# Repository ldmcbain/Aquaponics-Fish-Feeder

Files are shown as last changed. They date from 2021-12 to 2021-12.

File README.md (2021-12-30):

# Aquaponics Fish Feeder
 ESP32 Aquaponics Fish Feeder

This is a mod of a design I found in thingiverse:
https://www.thingiverse.com/thing:497637

This was designed using an ESP32 devkit board along with a 28BYJ-48 stepper motor and ULN2003 driver board (amazon).

The ESP32 is setup to create a WIFI captive portal page which is used to setup timing on the fish feeding intervals.  You can set the time/date on the device but know that it will loose the time/date on power reset.  However the feeding interval is stored in EEPROM, so it will just reset the clock to midnight and keep on going if power is interrupted.  This is designed only for a few fish, thus the small feeder holes.  The design was changed from the original as i found that the food we used would go underneath the original paddle wheels.

I also conformal coated the ESP board and driver board before deploying it (MG Chemicals - 422C-55MLCA 422C Silicone Conformal Coating - available from amazon)

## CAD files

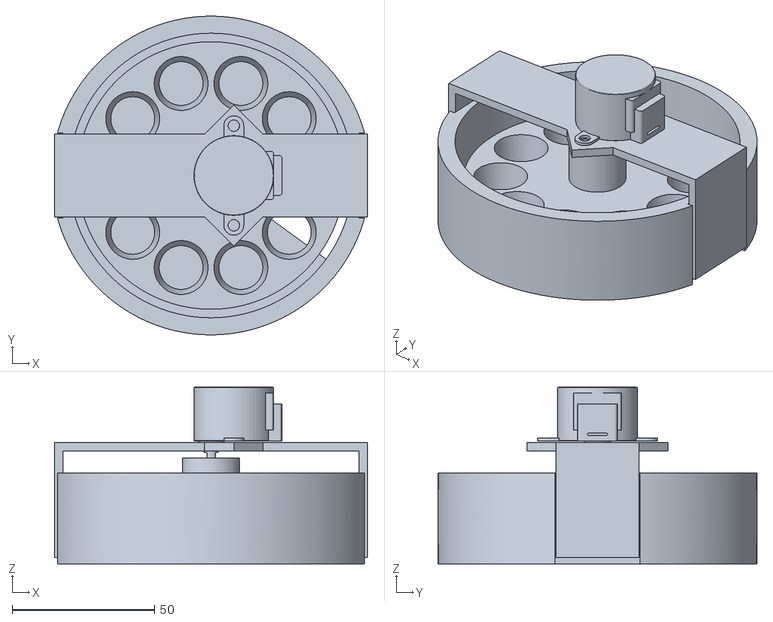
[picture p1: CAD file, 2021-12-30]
3D Printed Parts/Entire feeder.stl
110.0 x 112.0 x 62.1

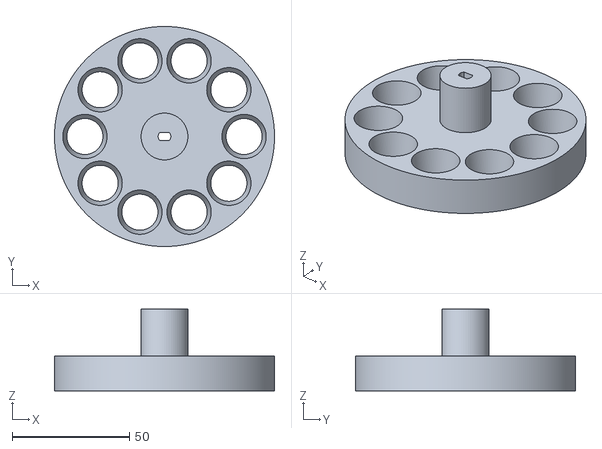
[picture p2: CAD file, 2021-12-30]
3D Printed Parts/NewDivider.stl
94.0 x 94.0 x 35.0

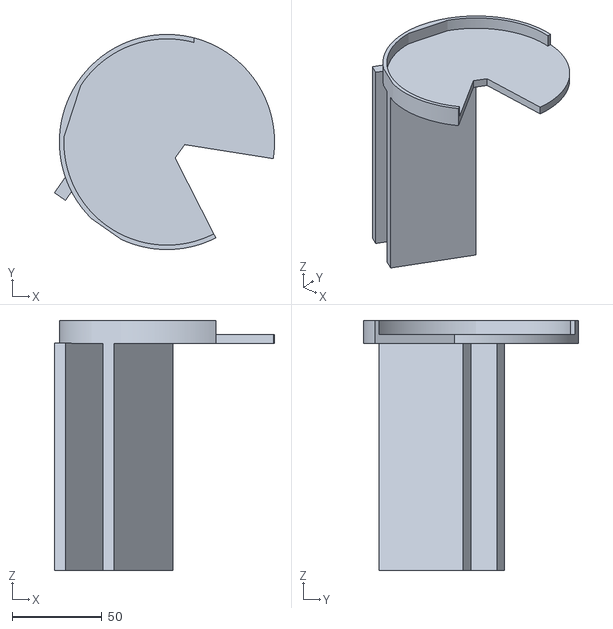
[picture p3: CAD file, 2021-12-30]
3D Printed Parts/feederBracket.stl
122.8 x 120.0 x 139.4

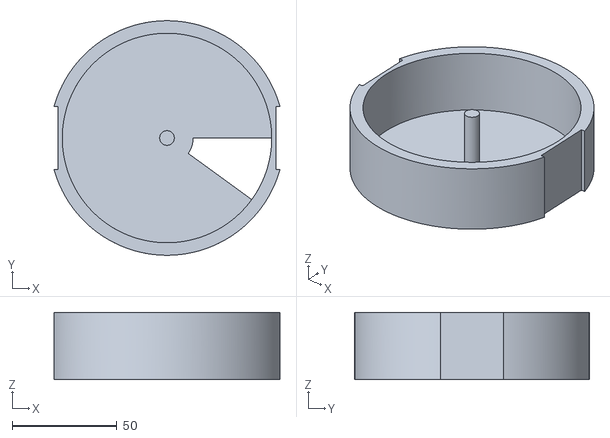
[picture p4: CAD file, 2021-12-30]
3D Printed Parts/Speedy_Feeder_v2_Container.stl
107.9 x 112.0 x 32.0

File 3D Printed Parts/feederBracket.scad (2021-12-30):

$fa=1;
$fs=1;

in=25.4;
th=5;
angle=-125;

%rotate([0,0,-18])
translate([0,0,th])
import("entire feeder.stl",convexity=4);
bracket();


module bracket()
{
    inner=115;
    difference()
    {
        cylinder(d=inner+th,h=0.5*in);
        translate([0,0,th])
        cylinder(d=inner,h=1*in);
        
        *translate([10,-inner/4,-th])
        cube([inner,inner/4,1*in]);
        
        rotate([0,0,-9])
        translate([0,0,-20])
        hull()
        {
            translate([10,0,0])
            cube([100,0.1,100]);
            rotate([0,0,-54])
            translate([10,0,0])
            cube([100,0.1,100]);
        }
        
        rotate([0,0,angle+90])
        translate([0,-50-inner/2-th/3,0])
        cube([100,100,600],center=true);
        
    
    translate([15,-10,th])
    cube([100,100,100]);
    }
    
    rotate([0,0,-18])
    translate([-inner/2-0.5,-30/2,0])
    cube([th/2,30,0.5*in]);
    
    rotate([0,0,angle])
    translate([0,-15,0])
    difference()
    {
        translate([th/3,-(1*in+th*3)/2,-4.99*in])
        cube([(inner)/2,1*in+th*3,5*in]);
        cube([(inner)*2,1*in,50*in],center=true);
    }
}

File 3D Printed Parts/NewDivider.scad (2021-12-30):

$fa=1;
$fs=1;
in=25.4;


difference()
{
    union()
    {//making small on purpose to reduce friction along edges
    cylinder(d=94,h=15);
    cylinder(d=20,h=35);
    }
    
    for(i=[0:10])
    {
        rotate([0,0,i*360/10])
        translate([34,0,25])
        {
        //scale([1,1,2])
        //sphere(d=24);
            
        cylinder(d1=0.375*in,d2=33,h=100,center=true);
        }
    }
    
    translate([0,0,-0.01])
    cylinder(d=9.5,h=30);
    
    intersection()
    {
        cylinder(d=5.5,h=100);
        cube([10,3.5,100],center=true);
    }
    
}

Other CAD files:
3D Printed Parts/Speedy_Feeder_v2_Divider_modv2.3mf
3D Printed Parts/Motor_Bracket.stl

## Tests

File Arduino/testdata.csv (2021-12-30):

20210708_0500 | wt | 70
20210708_0530 | wt | 71
20210708_0600 | wt | 70
20210708_0630 | wt | 71
20210708_0700 | wt | 70
20210708_0730 | wt | 71
20210708_0800 | wt | 70
20210708_0830 | wt | 71
20210708_0900 | wt | 70
20210708_0930 | wt | 71
20210708_1000 | wt | 70
20210708_1030 | wt | 70
20210708_1100 | wt | 71
20210708_1130 | wt | 70
20210708_1200 | wt | 71
20210708_1230 | wt | 70
20210708_1300 | wt | 71
20210708_1330 | wt | 70
20210708_1400 | wt | 71
20210708_1430 | wt | 70
20210708_1500 | wt | 71
20210708_1530 | wt | 70
20210708_1600 | wt | 71
20210708_1630 | wt | 70
20210708_1700 | wt | 70
20210708_1730 | wt | 70
20210708_1800 | wt | 70
20210708_1830 | wt | 70
20210708_1900 | wt | 70
20210708_1930 | wt | 70
20210708_2000 | wt | 70
20210708_2030 | wt | 70
20210708_2100 | wt | 70
20210708_2130 | wt | 70
20210708_2200 | wt | 71

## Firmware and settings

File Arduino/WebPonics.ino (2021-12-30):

/*
 * ENDEAVOR Web based Aquaponics Controller
 * This project was created by Endeavor Labs (a mission of Endeavor Church) to create
 * an Arduino based controller to service an aquaponics setup meant for a class setting.
 * 
 * The system is to be designed to use a ESP32 Dev board to control:
 *  - 3D printed fish feeder driven by servo motor
 *      Based on https://www.thingiverse.com/thing:4627735, modified to hook onto tank
 *  - Water temperature sensor
 *  - Air Temperature/Humidity sensor
 *  - Water level sensor
 *  - Pump cutoff based upon low water level reading
 *  - Real Time Clock (RTC) / Data loger (SD card) used for obtaining date/time for feeding etc
 *  - Web based interface for viewing data, manual feed control, data log entry and viewing. (stored on SD card)
 * 
 * This software is designed to create a permanent Access Point with a captive portal
 * to a webpage which will control the Feeder and view/monitor sensors and logs as noted above
 * 
 * Will utilize Plotly JS script library (plotly.js stored in SPIFFS) to view data graphs.
 * Stored data logs and sensor logs will be stored on SD card
 * 
 * I have found partial plotly files which will likely work and are much smaller.  using minimized basic package located here:
 * https://github.com/plotly/plotly.js/blob/master/dist/README.md
 * also possible to create own package customized to only what I need:
 * https://github.com/plotly/plotly.js/blob/master/CUSTOM_BUNDLE.md
 * Note: I may have issues w/ plotly as it is LARGE and unsure how to reference a JS file on an SD card.
 * Alternatives may be required.
 * https://forum.arduino.cc/t/arduino-mega-json-rest-interfaces-for-html-guis/126471/9
 * 
 * 
 * Note for possible future upgrade.. ability to upload data directly to web based server.
 * current use is offline-only.
 *      https://github.com/plotly/arduino-api
 *      https://www.instructables.com/Plotly-Arduino-Data-Visualization/
 * 
 * This version is based upon initial work with the Endeavor Sign V2 and is using that project
 * as a base.  It may possibly also utilize the Endeavor Labs ESP32 board.
 * 
 * Board - ESP32S Dev Module (thin version of ESP module [22.86mm pin width] from HiLetgo ESP-WROOM-32S)
 *          I believe this is a NodeMCU ESP32S board design https://www.amazon.com/gp/product/B0718T232Z/ref=ppx_yo_dt_b_search_asin_title?ie=UTF8&psc=1)
 * Upload Speed - 115200
 * CPU Freq - 240MHz
 * Flash Freq 40MHz
 * Mode - QIO
 * Flash size - 4MB (32Mb)
 * Partition - Default 4MB wigh SPIFFS (1.2MB APP/1.5MB SPIFFS)
 */

#include <Arduino.h>
#include <WebServer.h>
#include <DNSServer.h>
#include "./server_html.h"
#include "./myeeprom.h"
#include <SPIFFS.h>
#include <Wire.h>
#include "RTClib.h"
#include "DST_RTC.h"

#define FILESYSTEM SPIFFS

//motor pins
#define MOTOR_A 12
#define MOTOR_B 13
#define MOTOR_C 14
#define MOTOR_D 15
#define NUMBER_OF_STEPS_PER_REV 512


// Replace with your network credentials
const char* ssid     = "AQUA_P_";
const char* password = NULL;  //making this an open access?

// Set web server port number to 80
WebServer server(80);
const byte DNS_PORT = 53;
IPAddress apIP(192, 168, 1, 1);
DNSServer dnsServer;

RTC_DS1307 rtc; // clock object
DST_RTC dst_rtc; // DST object
const char rulesDST[]="US";

uint8_t Alarm1, Alarm2, Alarm3, Alarm4;

void handleRoot()
{
  buildWebsite();
  server.send(200, "text/html", webSite);
}

void handleFeed()
{
  //Manually engage servo to feed fish
  Serial.printf("%02i/%02i/%i_%02i:%02i:%02i - Feeding Fish..\n",month(),day(),year(),hour(),minute(),second());
  moveDeg(36);
  MotorOff();
}

void handleSetTime()
{
  //set the time based upon something from the website..
  //Serial.printf("attempting to set time to: %s/%s/%s %s:%s:%s",server.arg("MM"),server.arg("D"),server.arg("Y"),server.arg("H"),server.arg("m"),server.arg("s"));
  //Serial.println("");
  settime(atoi(server.arg("MM").c_str()),
          atoi(server.arg("D").c_str()),
          atoi(server.arg("Y").c_str()),
          atoi(server.arg("H").c_str()),
          atoi(server.arg("m").c_str()),
          atoi(server.arg("s").c_str()));
}

void settime(int Month, int Day, int Year, int Hour, int Min, int Sec)
{
  //set the RTC time clock
  rtc.adjust(DateTime(Year, Month, Day, Hour, Min, Sec));
  Serial.printf("Time set to: %02i/%02i/%i %02i:%02i:%02i",Month,Day,Year,Hour,Min,Sec);
  Serial.println("");
  //init time for time.h
  setTime(Hour, Min, Sec, Day, Month, Year);
  
  // DST? If we're in it, let's subtract an hour from the RTC time to keep our DST calculation correct. This gives us
  // Standard Time which our DST check will add an hour back to if we're in DST.
  DateTime standardTime = now();
  if (dst_rtc.checkDST(standardTime) == true) { // check whether we're in DST right now. If we are, subtract an hour.
    standardTime = standardTime.unixtime() - 3600;
    rtc.adjust(standardTime);
    Serial.println("Time adjusted for Daylight Savings Time");
  }
}

//function will parse out a time in string format "HH:MMam" to integers
void ParseTime(char* Instr, int* Hour, int* Min, bool* AM)
{
  //char param[10];
  char out[3] = "";
  int colon;
  colon=0;
  //strcopy(param,Instr);
  for(int i=0;i<strlen(Instr);i++)
  {
    if(Instr[i]==':')
    {
      out[i]=0;
      *Hour=atoi(out);
      colon=i+1;
      out[0]=0;
    } else if((Instr[i]!='a') && (Instr[i]!='p'))
    {
      out[i-colon]=Instr[i];
    } else
    {
      out[i]=0;
      *Min=atoi(out);
      if(Instr[i]=='a') *AM=true; else *AM=false;
    }
  }
}

//clear existing alarms and set new ones.
void handleSetAlarms()
{
  int Hour, Min;
  bool AM;
  char instr[10];

  if(Alarm.isAllocated(Alarm1))
  {
    Alarm.disable(Alarm1);
    Alarm.free(Alarm1);
    Serial.println("Alarm1 Freed");
  }
  if(Alarm.isAllocated(Alarm2))
  {
    Alarm.disable(Alarm2);
    Alarm.free(Alarm2);
    Serial.println("Alarm1 Freed");
  }
  if(Alarm.isAllocated(Alarm3))
  {
    Alarm.disable(Alarm3);
    Alarm.free(Alarm3);
    Serial.println("Alarm1 Freed");
  }
  if(Alarm.isAllocated(Alarm4))
  {
    Alarm.disable(Alarm4);
    Alarm.free(Alarm4);
    Serial.println("Alarm1 Freed");
  }
  
  if(server.hasArg("E1"))
  {
    strcpy(instr,server.arg("E1").c_str());
    T1_time = server.arg("E1");
    ParseTime(instr,&Hour,&Min, &AM);
    if(AM && (Hour==12)) Hour = 0;
    if(!AM && (Hour!=12)) Hour += 12;
    Serial.printf("Event1 set for: %02i:%02i:00\n",Hour,Min);
    //sprintf(T1_time,"%02i:%02i\n",Hour,Min);
    T1_e = true;

    Alarm1 = Alarm.alarmRepeat(Hour,Min,0,handleFeed);
  } else T1_e = false;
  if(server.hasArg("E2"))
  {
    strcpy(instr,server.arg("E2").c_str());
    T2_time = server.arg("E2");
    ParseTime(instr,&Hour,&Min, &AM);
    if(AM && (Hour==12)) Hour = 0;
    if(!AM && (Hour!=12)) Hour += 12;
    Serial.printf("Event2 set for: %02i:%02i:00\n",Hour,Min);
    T2_e = true;
    
    Alarm2 = Alarm.alarmRepeat(Hour,Min,0,handleFeed);
  } else T2_e = false;
  if(server.hasArg("E3"))
  {
    strcpy(instr,server.arg("E3").c_str());
    T3_time = server.arg("E3");
    ParseTime(instr,&Hour,&Min, &AM);
    if(AM && (Hour==12)) Hour = 0;
    if(!AM && (Hour!=12)) Hour += 12;
    Serial.printf("Event3 set for: %02i:%02i:00\n",Hour,Min);
    //sprintf(T3_time,"%02i:%02i\n",Hour,Min);
    T3_e = true;
  
    Alarm3 = Alarm.alarmRepeat(Hour,Min,0,handleFeed);
  } else T3_e = false;
  if(server.hasArg("E4"))
  {
    strcpy(instr,server.arg("E4").c_str());
    T4_time = server.arg("E4");
    ParseTime(instr,&Hour,&Min, &AM);
    if(AM && (Hour==12)) Hour = 0;
    if(!AM && (Hour!=12)) Hour += 12;
    Serial.printf("Event4 set for: %02i:%02i:00\n",Hour,Min);
    //sprintf(T4_time,"%02i:%02i\n",Hour,Min);
    T4_e = true;
  
    Alarm4 = Alarm.alarmRepeat(Hour,Min,0,handleFeed);
  } else T4_e = false;
  handleSAVE();
}


time_t syncProvider()
{
  DateTime standardTime = rtc.now();
  
  DateTime theTime = dst_rtc.calculateTime(standardTime); // takes into account DST
  return theTime.unixtime();
}


void handleSAVE()
{
  Serial.println("Saving Settings");
  
  Serial.printf("T1-%s %s\n",T1_time,T1_e ? "Enabled" : "Disabled");
  Serial.printf("T2-%s %s\n",T2_time,T2_e ? "Enabled" : "Disabled");
  Serial.printf("T3-%s %s\n",T3_time,T3_e ? "Enabled" : "Disabled");
  Serial.printf("T4-%s %s\n",T4_time,T4_e ? "Enabled" : "Disabled");
  
  saveSettings(T1_time,T2_time,T3_time,T4_time,T1_e,T2_e,T3_e,T4_e);
}

void handleRESTORE()
{
  int Hour, Min;
  bool AM;
  char instr[10];
  
  getStoredSettings();
  T1_time=String(romSettings.T1);
  T2_time=String(romSettings.T2);
  T3_time=String(romSettings.T3);
  T4_time=String(romSettings.T4);
  T1_e = romSettings.T1_enable;
  T2_e = romSettings.T2_enable;
  T3_e = romSettings.T3_enable;
  T4_e = romSettings.T4_enable;

  if(T1_e)
  {
    strcpy(instr,T1_time.c_str());
    ParseTime(instr,&Hour,&Min, &AM);
    if(AM && (Hour==12)) Hour = 0;
    if(!AM && (Hour!=12)) Hour += 12;
    Serial.printf("Event1 set for: %02i:%02i:00\n",Hour,Min);  
    Alarm1 = Alarm.alarmRepeat(Hour,Min,0,handleFeed);
  }
  if(T2_e)
  {
    strcpy(instr,T2_time.c_str());
    ParseTime(instr,&Hour,&Min, &AM);
    if(AM && (Hour==12)) Hour = 0;
    if(!AM && (Hour!=12)) Hour += 12;
    Serial.printf("Event2 set for: %02i:%02i:00\n",Hour,Min);  
    Alarm2 = Alarm.alarmRepeat(Hour,Min,0,handleFeed);
  }
  if(T3_e)
  {
    strcpy(instr,T3_time.c_str());
    ParseTime(instr,&Hour,&Min, &AM);
    if(AM && (Hour==12)) Hour = 0;
    if(!AM && (Hour!=12)) Hour += 12;
    Serial.printf("Event3 set for: %02i:%02i:00\n",Hour,Min);  
    Alarm3 = Alarm.alarmRepeat(Hour,Min,0,handleFeed);
  }
  if(T4_e)
  {
    strcpy(instr,T4_time.c_str());
    ParseTime(instr,&Hour,&Min, &AM);
    if(AM && (Hour==12)) Hour = 0;
    if(!AM && (Hour!=12)) Hour += 12;
    Serial.printf("Event4 set for: %02i:%02i:00\n",Hour,Min);  
    Alarm4 = Alarm.alarmRepeat(Hour,Min,0,handleFeed);
  }
}

//function will parse out a time in string format "HH:MMam" to integers
void parseStored(char* Instr, int* Hour, int* Min, bool* AM)
{
  //char param[10];
  char out[3] = "";
  int colon;
  colon=0;
  //strcopy(param,Instr);
  for(int i=0;i<strlen(Instr);i++)
  {
    if(Instr[i]==':')
    {
      out[i]=0;
      *Hour=atoi(out);
      colon=i+1;
      out[0]=0;
    } else if((Instr[i]!='a') && (Instr[i]!='p'))
    {
      out[i-colon]=Instr[i];
    } else
    {
      out[i]=0;
      *Min=atoi(out);
      if(Instr[i]=='a') *AM=true; else *AM=false;
    }
  }
}

void setup() {
  Serial.begin(115200);
  
  //Initialize Clock
  Wire.begin();
  rtc.begin();
  
  /*
    This line sets the RTC with an explicit date & time (standard time - not DST), for example to set
    March 28, 2020 at 23:58:5 you would call:
    // rtc.adjust(DateTime(2020, 3, 28, 23, 58, 5));
    If used load the sketch a second time with this line commented out or the RTC will reset to
    this time on power up or reset.
  */
  
  if (! rtc.isrunning()) {
    Serial.println("RTC is NOT running!");
    // following line sets the RTC to the date & time this sketch was compiled
    rtc.adjust(DateTime(__DATE__, __TIME__));
    // DST? If we're in it, let's subtract an hour from the RTC time to keep our DST calculation correct. This gives us
    // Standard Time which our DST check will add an hour back to if we're in DST.
    /*
    DateTime standardTime = rtc.now();
    if (dst_rtc.checkDST(standardTime) == true) { // check whether we're in DST right now. If we are, subtract an hour.
      standardTime = standardTime.unixtime() - 3600;
      rtc.adjust(standardTime);
    }
    */
    
  }
  //setSyncProvider(syncProvider);
  if (timeStatus()!=timeSet)
  {
    //give a default time if power lost so feeder will continue.
    settime(1,1,2021,1,0,0);
  }

  //may need to comment this out for the 1st run to init the save points first
  handleRESTORE();

  //Create and initialize alarms
  /*Alarm1 = Alarm.alarmRepeat(0,0,0,nullFunction);
  Alarm2 = Alarm.alarmRepeat(1,0,0,nullFunction);
  Alarm3 = Alarm.alarmRepeat(2,0,0,nullFunction);
  Alarm4 = Alarm.alarmRepeat(3,0,0,nullFunction);
  Alarm.disable(Alarm1);
  Alarm.disable(Alarm2);
  Alarm.disable(Alarm3);
  Alarm.disable(Alarm4);*/
  //todo - load from eprom stored values.

  // Initialize SPIFFS
  if(!FILESYSTEM.begin(true)){
    Serial.println("An Error has occurred while mounting SPIFFS");
    return;
  }
  
  // Connect to Wi-Fi network with SSID and password
  Serial.print("Starting AP ");
  Serial.println(ssid);

  //set SSID based upon the mac address of the device (in case we have multiple)
  //strcat(ssid,WiFi.softAPmacAddress().c_str());
  WiFi.mode(WIFI_AP);
  Serial.println(WiFi.softAP(ssid, password) ? "soft-AP setup": "Failed to connect");
  delay(100);
  Serial.println(WiFi.softAPConfig(apIP, apIP, IPAddress(255, 255, 255, 0))? "Configuring Soft AP" : "Error in Configuration");


  //setup captive portal so all traffic goes to main page
  dnsServer.start(DNS_PORT, "*", apIP);
  
  Serial.println("");
  Serial.println("WiFi connected.");
  Serial.print("IP:");
  Serial.println(WiFi.softAPIP());
  startWebServer();

  
  pinMode(MOTOR_A,OUTPUT);
  pinMode(MOTOR_B,OUTPUT);
  pinMode(MOTOR_C,OUTPUT);
  pinMode(MOTOR_D,OUTPUT);
}

void loop(){
  //DateTime standardTime = rtc.now();

  //Serial.println("Standard Time");
  //printTheTime(standardTime);
  
  //DateTime theTime = dst_rtc.calculateTime(standardTime); // takes into account DST

  //Serial.println("time adjusted for Daylight Saving Time");
  //printTheTime(theTime);
  
  dnsServer.processNextRequest();
  server.handleClient();
  Alarm.delay(1);
}


// print time to serial
void printTheTime(DateTime theTimeP) {
  Serial.print(theTimeP.year(), DEC);
  Serial.print('/');
  Serial.print(theTimeP.month(), DEC);
  Serial.print('/');
  Serial.print(theTimeP.day(), DEC);
  Serial.print(' ');
  Serial.print(theTimeP.hour(), DEC);
  Serial.print(':');
  Serial.print(theTimeP.minute(), DEC);
  Serial.print(':');
  Serial.print(theTimeP.second(), DEC);
  Serial.println();
}

void startWebServer()
{  
  //setup to send files stored in SPIFFS when requested
  server.on("/plotly-basic.js", HTTP_GET, [](){
    if (!handleFileRead("/plotly-basic.js")) {
      server.send(404, "text/plain", "FileNotFound");
    }
  });
  server.on("/GridStyle.css", HTTP_GET, [](){
    if (!handleFileRead("/GridStyle.css")) {
      server.send(404, "text/plain", "FileNotFound");
    }
  });
  server.on("/MainStyle.css", HTTP_GET, [](){
    if (!handleFileRead("/MainStyle.css")) {
      server.send(404, "text/plain", "FileNotFound");
    }
  });
  server.on("/jquery-3.6.0.slim.min.js", HTTP_GET, [](){
    if (!handleFileRead("/jquery-3.6.0.slim.min.js")) {
      server.send(404, "text/plain", "FileNotFound");
    }
  });
  server.on("/jquery.timepicker.js", HTTP_GET, [](){
    if (!handleFileRead("/jquery.timepicker.js")) {
      server.send(404, "text/plain", "FileNotFound");
    }
  });
  server.on("/jquery.timepicker.css", HTTP_GET, [](){
    if (!handleFileRead("/jquery.timepicker.css")) {
      server.send(404, "text/plain", "FileNotFound");
    }
  });
  server.on( "/", handleRoot);
  server.on("/settime",handleSetTime);
  server.on("/feed",handleFeed);
  server.on("/savealarms",handleSetAlarms);
  server.onNotFound(handleRoot);
  server.begin();
}

bool handleFileRead(String path) {
  String contentType = getContentType(path);
  if (exists(path)) {
    File file = FILESYSTEM.open(path, "r");
    server.streamFile(file, contentType);
    file.close();
    return true;
  }
  return false;
}

String getContentType(String filename) {
  if (server.hasArg("download")) {
    return "application/octet-stream";
  } else if (filename.endsWith(".htm")) {
    return "text/html";
  } else if (filename.endsWith(".html")) {
    return "text/html";
  } else if (filename.endsWith(".css")) {
    return "text/css";
  } else if (filename.endsWith(".js")) {
    return "application/javascript";
  } else if (filename.endsWith(".png")) {
    return "image/png";
  } else if (filename.endsWith(".gif")) {
    return "image/gif";
  } else if (filename.endsWith(".jpg")) {
    return "image/jpeg";
  } else if (filename.endsWith(".ico")) {
    return "image/x-icon";
  } else if (filename.endsWith(".xml")) {
    return "text/xml";
  } else if (filename.endsWith(".pdf")) {
    return "application/x-pdf";
  } else if (filename.endsWith(".zip")) {
    return "application/x-zip";
  } else if (filename.endsWith(".gz")) {
    return "application/x-gzip";
  }
  return "text/plain";
}

bool exists(String path){
  bool yes = false;
  File file = FILESYSTEM.open(path, "r");
  if(!file.isDirectory()){
    yes = true;
  }
  file.close();
  return yes;
}


void Motorwrite(int a,int b,int c,int d){
digitalWrite(MOTOR_A,a);
digitalWrite(MOTOR_B,b);
digitalWrite(MOTOR_C,c);
digitalWrite(MOTOR_D,d);
}

void MotorOff()
{
Motorwrite(0,0,0,0);
}

void onestepfwd(int delayval){
Motorwrite(1,0,0,0);
Alarm.delay(delayval);
Motorwrite(1,1,0,0);
Alarm.delay(delayval);
Motorwrite(0,1,0,0);
Alarm.delay(delayval);
Motorwrite(0,1,1,0);
Alarm.delay(delayval);
Motorwrite(0,0,1,0);
Alarm.delay(delayval);
Motorwrite(0,0,1,1);
Alarm.delay(delayval);
Motorwrite(0,0,0,1);
Alarm.delay(delayval);
Motorwrite(1,0,0,1);
Alarm.delay(delayval);
}

void onestepbck(int delayval){
Motorwrite(0,0,0,1);
Alarm.delay(delayval);
Motorwrite(0,0,1,1);
Alarm.delay(delayval);
Motorwrite(0,0,1,0);
Alarm.delay(delayval);
Motorwrite(0,1,1,0);
Alarm.delay(delayval);
Motorwrite(0,1,0,0);
Alarm.delay(delayval);
Motorwrite(1,1,0,0);
Alarm.delay(delayval);
Motorwrite(1,0,0,0);
Alarm.delay(delayval);
Motorwrite(1,0,0,1);
Alarm.delay(delayval);
}

void moveDeg(float degree)
{
  int i;
  if(degree>0){for(i=0;i<((degree/360)*NUMBER_OF_STEPS_PER_REV);i++){onestepfwd(10);}}
  else{for(i=0;i>((degree/360)*NUMBER_OF_STEPS_PER_REV);i--){onestepbck(10);}}
}

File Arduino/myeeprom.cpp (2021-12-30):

#include "./myeeprom.h"


StoredSettings romSettings;



/**
 * Retrieves stored settings from EEPROM so that WiFi setup does not have to be repeated on every power cycle
 * 
 * @return struct
 * @author costmo
 * @since  20180929
 */
StoredSettings getStoredSettings()
{
  uint addr = 0;
  EEPROM.begin( 512 );
  EEPROM.get( addr, romSettings );
  EEPROM.end();
  /*
  Serial.println("EEPROM c_str RESTORE values:");
  Serial.printf("R1:%s G1:%s B1:%s W1:%s ",romSettings.RD1,romSettings.GR1,romSettings.BL1,romSettings.WH1);
  Serial.printf("R2:%s G2:%s B2:%s W2:%s ",romSettings.RD2,romSettings.GR2,romSettings.BL2,romSettings.WH2);
  Serial.printf("R3:%s G3:%s B3:%s W3:%s ",romSettings.RD3,romSettings.GR3,romSettings.BL3,romSettings.WH3);
  Serial.println("");
  */
  return romSettings;
}


/**
 * Stores the input settings to EEPROM
 * 
 * @return void
 * @author costmo
 * @since  20180929
 */
void saveSettings(String t1, String t2, String t3, String t4, bool t1e, bool t2e, bool t3e, bool t4e)
{
  uint addr = 0;

  strcpy( romSettings.T1, t1.c_str() );
  strcpy( romSettings.T2, t2.c_str() );
  strcpy( romSettings.T3, t3.c_str() );
  strcpy( romSettings.T4, t4.c_str() );
  romSettings.T1_enable=t1e;
  romSettings.T2_enable=t2e;
  romSettings.T3_enable=t3e;
  romSettings.T4_enable=t4e;
  
/*
  Serial.println("EEPROM c_str values:");
  Serial.printf("R1:%s G1:%s B1:%s W1:%s ",romSettings.RD1,romSettings.GR1,romSettings.BL1,romSettings.WH1);
  Serial.printf("R2:%s G2:%s B2:%s W2:%s ",romSettings.RD2,romSettings.GR2,romSettings.BL2,romSettings.WH2);
  Serial.printf("R3:%s G3:%s B3:%s W3:%s ",romSettings.RD3,romSettings.GR3,romSettings.BL3,romSettings.WH3);
  Serial.println("");
*/
  EEPROM.begin( 512 );
  EEPROM.put( addr, romSettings );
  EEPROM.end();
}
